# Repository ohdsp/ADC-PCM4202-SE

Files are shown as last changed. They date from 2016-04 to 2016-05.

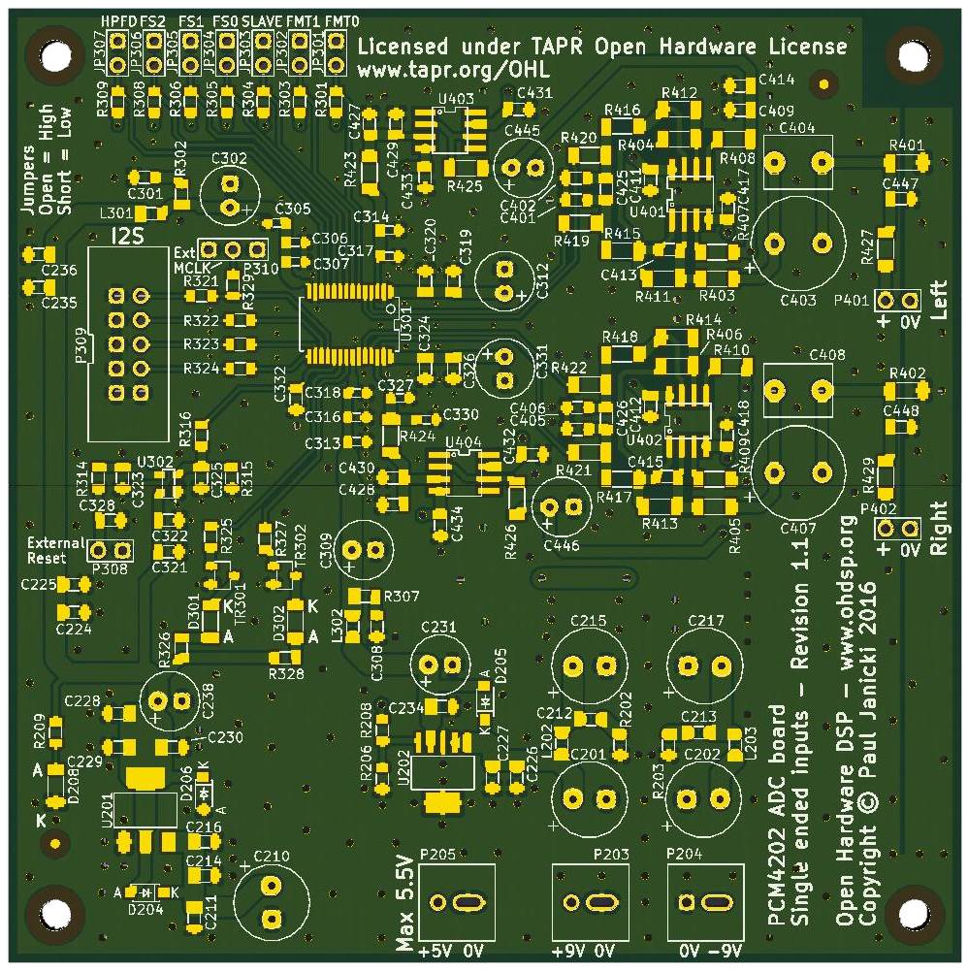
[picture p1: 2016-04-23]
ADC-PCM4202-SE.jpg

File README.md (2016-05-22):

# [Open Hardware DSP Platform](http://www.ohdsp.org)
## PCM4202 ADC with single ended inputs
### Revision 1.1
###### ADC-PCM4202-SE (KiCad 4.0.2-stable)
---
# README
### Disclaimer
Copyright Paul Janicki 2016

Licensed under the TAPR Open Hardware License (www.tapr.org/OHL)

This documentation is distributed WITHOUT ANY EXPRESS OR IMPLIED WARRANTY, INCLUDING OF MERCHANTABILITY, SATISFACTORY QUALITY AND FITNESS FOR A PARTICULAR PURPOSE.

### What is this repository?

**Quick summary**

This is a single ended stereo input PCM4202 ADC. This is designed as part the Open Hardware DSP Platform.  

The PCM4202 is a hardware controlled Delta-Sigma ADC.

This repository contains the KiCad design files, manufacturing Gerber/drill files, and PDF/drawing files for this board.

### What is the project folder structure?
Starting from the top level: \
*ADC-PCM4202-SE*
+ *Bill of Materials*  - This contains the bill of materials in CVS, LibreOffice Calc and XML formats
+ *Drawings*
    + *PCB* - This contains SVG and PDF outputs of PCB copper layers and assembly drawings
    + *Schematics* - This contains the PDF schematic drawing
+ *Gerbers* - This contains the PCB Gerbers and drill drawings for manufacture, there is also a zip file ready to send to most manufacturers
+ *KiCad* - This contains the original KiCad schematic and PCB design files

### How do I get set up?

**Summary of set up**

1. Set your self up a directory on a local disk, something simple will make life easier (eg C:\Electronics on Windows as used here), but anywhere will do just fine.
2. Download the Kicad-Libs from [https://github.com/ohdsp/KiCad-Libs](https://github.com/ohdsp/KiCad-Libs) and place in C:\Electronics\Kicad-Libs (or your chosen folder) 
3. Create a OHDSP subdirectory in C:\Electronics (so C:\Electronics\OHDSP)
3. Download this project to C:\Electronics\OHDSP\ADC-PCM4202-SE
4. Fire up Kicad
5. Open the main project file C:\Electronics\OHDSP\ADC-PCM4202-SE\Schematics\ADC-PCM4202-SE.pro
6. (Optional) Setup Pcbnew component library as below.
7. Do as you wish with the project, just keep it under TAPR Open Hardware License

Make sure your git setup doesn't exclude files used in the project (like .LIB files) or things may go wrong down the line.

**KiCad Library Configuration**

Note that you need to setup a Pcbnew library, but the eeschema libraries should work without any changes if you followed the instructions above.

To setup Pcbnew libraries:

In Pcbnew go to Preferences -> Footprint Libraries Manager. Under Global Libraries tab in the top list check if there is a nickname "MyKiCadLibs-Footprints" (usually at the end of the list). If there is but it points to the wrong place then change the Library Path to point to MyKiCadLibs-Footprints (eg C:\Electronics\KiCad-Libs\MyKiCadLibs-Footprints.pretty) folder for your setup. If this is missing you can use "Append with Wizard", choose "Files on my computer", click next, browse to library location (eg C:\Electronics\KiCad-Libs\MyKiCadLibs-Footprints.pretty) and select the folder MyKiCadLibs-Footprints.pretty, click next, check the Status column states OK and the Format is KiCad (if not re-download the library) and click next, then select "To global library configuration..." and click Finish.

To setup eeschema component libraries:
Either from KiCad project window go to Tools -> Run Library Editor OR under eeschema, go to Tools -> Library Editor. Then Preferences -> Component Libraries.

The top section "Component Library Files" should ideally contain only two libraries, the "power" library that ships with KiCad and "MyKiCadLibs-Lib" available from above. To setup MyKiCadLibs-Lib as a relative path under the "User defined search path" click add. Browse to the location of KiCad-Libs you download above (eg C:\Electronics\KiCad-Libs) and click "Select Folder". Say yes to add a relative path. Under component library files click add, browse to the KiCad-libs again (eg C:\Electronics\KiCad-Libs), select file "MyKiCadLibs-Lib.lib" and click open. MyKiCadLibs-lib should appear in the component library list with no path as it will be using the user defined search path set in the box below.

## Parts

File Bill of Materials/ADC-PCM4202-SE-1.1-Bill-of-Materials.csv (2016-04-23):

Reference | Quantity | Footprint | Value | Description | Voltage | Size | Current | Type | Tolerance | Power
C201 C202 C210 C215 C217 | 5 | CAP-TH-D8mmP3.5mm | 220u | 'Aluminium electrolytic low impedance capacitor - eg Panasonic FC or FR parts | '25V | '3.5mm Pitch, 8mm Diameter | ' | ' | ' | '
C203 C204 C211 C218 C219 C226 | 6 | SMD-0805 | 22u | 'Ceramic capacitor | '25V | '0805 | ' | 'X5R | '20% | '
C205 C206 C214 C220 C221 C225 C227 C229 C233 C236 C237 C304 C311 C319 C322 C323 C326 C328 C332 C409 C410 C411 C412 C417 C418 C421 C422 C427 C428 C431 C432 C433 C434 C437 C438 C441 C442 C449 C450 | 39 | SMD-0805 | 100n | 'Ceramic capacitor | '50V | '0805 | ' | 'X7R | '10% | '
C208 C209 C216 C222 C223 C230 C234 C320 C324 C423 C424 C429 C430 C439 C440 C443 C444 | 17 | SMD-0805 | 10n | 'Ceramic capacitor | '50V | '0805 | ' | 'X7R | '10% | '
C207 C212 C213 C301 C308 C401 C402 C405 C406 | 9 | SMD-0805 | 100p | 'Ceramic capacitor | '50V | '0805 | ' | 'C0G | '5% | '
C224 C235 C321 C414 C416 C451 C452 | 7 | SMD-0805 | 10u | 'Ceramic capacitor | '10V | '0805 | ' | 'X5R | '20% | '
C231 C238 C302 C309 C312 C331 | 6 | CAP-TH-D6.3mmP2.5mm | 220u | 'Aluminium electrolytic low impedance capacitor - eg Panasonic FC or FR parts | '10V | '2.5mm Pitch, 6.3mm Diameter | ' | ' | ' | '
C228 C232 C303 C310 C315 C329 | 6 | SMD-0805 | 22u | 'Ceramic capacitor | '10V | '0805 | ' | 'X5R | '20% | '
C305 C313 | 2 | SMD-0603 | 1u | 'Ceramic capacitor | '10V | '0603 | ' | 'X7R | '10% | '
C306 C314 C316 C330 | 4 | SMD-0603 | 100n | 'Ceramic capacitor | '50V | '0603 | ' | 'X7R | '10% | '
C307 C317 C318 C327 | 4 | SMD-0603 | 10n | 'Ceramic capacitor | '50V | '0603 | ' | 'X7R | '10% | '
C325 | 1 | SMD-0805 | N/F | 'Ceramic capacitor | '50V | '0805 | ' | 'X7R | '10% | '
C403 C407 | 2 | CAP-TH-D10mmP5mm | 100u | 'Aluminium electrolytic - Panasonic FC, Audio Grade, or Bipolar part | '50V | '5mm Pitch, 10mm Diameter | ' | ' | ' | '
C404 C408 | 2 | CAP_TH_5mm | 100n | 'Polyester capacitor - 5mm pitch - 5.5mm width max | '63V | '5mm | ' | 'Film | '10% | '
C413 C415 | 2 | SMD-0805 | 330p | 'Ceramic capacitor | '50V | '0805 | ' | 'C0G | '5% | '
C419 C420 C435 C436 | 4 | SMD-1206 | 10u | 'Ceramic capacitor | '35V | '1206 | ' | 'X5R | '20% | '
C425 C426 | 2 | SMD-0805 | 2n7 | 'Ceramic capacitor | '50V | '0805 | ' | 'C0G | '5% | '
C445 C446 | 2 | CAP-TH-D6.3mmP2.5mm | 47u | 'Aluminium electrolytic low impedance capacitor - eg Panasonic FC or FR parts | '10V | '2.5mm Pitch, 6.3mm Diameter | ' | ' | ' | '
C447 C448 | 2 | SMD-0805 | 1n | 'Ceramic capacitor | '50V | '0805 | ' | 'C0G | '5% | '
D201 D202 D203 D204 D205 D206 D207 | 7 | DIODE-SOD-123 | SS14L | 'SS14L 1A 40V Schottky rectifier - Sub-SMA (SOD-123) | ' | ' | ' | ' | ' | '
D208 | 1 | SMD-1206 | Green LED 1206 | 'Green LED - SMD - Vf 1.8V to 2.2V | ' | '1206 | ' | ' | ' | '
D301 D302 | 2 | SMD-1206 | Red LED 1206 | 'Red LED - SMD - Vf 1.8V to 2.2V | ' | '1206 | ' | ' | ' | '
FID1 FID2 FID3 FID4 | 4 | FID-1MM-3MM | MNT_HOLE | 'Fiducial Marker | ' | ' | ' | ' | ' | '
JP301 JP302 JP303 JP304 JP305 JP306 JP307 P308 P401 P402 | 10 | CONN_SIL_2_1MM | CONN_2x1 | '1x2 2.54mm pitch pin header | ' | ' | ' | ' | ' | '
L201 L202 L203 L301 L302 | 5 | SMD-0805 | 600R@100MHz | 'Ferrite bead, current rating 0.3A or higher, 600R@100MHz | ' | '0805 | '=>0.3A | ' | ' | '
MNT201 MNT202 MNT203 MNT204 | 4 | MNT_HOLE_3.2mm | MNT_HOLE | 'Mounting Hole | ' | ' | ' | ' | ' | '
P203 P204 P205 | 3 | CONN-2WAY-2.54mm-3.81mm-SPACING | CONN_2x1 | '2 way screw terminal, any 2.54mm to 3.81mm pitch part | ' | ' | ' | ' | ' | '
P309 | 1 | CONN_DIL_2X5_BOX_1MM | CONN_02X05 | '2x5 2.54mm pitch box header | ' | ' | ' | ' | ' | '
P310 | 1 | CONN_SIL_3_1MM | N/F | '1x3 2.54mm pitch pin header | ' | ' | ' | ' | ' | '
R201 R202 R203 R302 R307 | 5 | SMD-0805 | 47 | 'Thick or thin film resistor | ' | '0805 | ' | ' | '1% | '100mW
R206 | 1 | SMD-0805 | 2k2 | 'Thick or thin film resistor | ' | '0805 | ' | ' | '1% | '100mW
R208 | 1 | SMD-0805 | 6k8 | 'Thick or thin film resistor | ' | '0805 | ' | ' | '1% | '100mW
R209 R326 R328 | 3 | SMD-0805 | 470 | 'Thick or thin film resistor | ' | '0805 | ' | ' | '1% | '100mW
R301 R303 R304 R305 R306 R308 R309 | 7 | SMD-0805 | 10k | 'Thick or thin film resistor | ' | '0805 | ' | ' | '1% | '100mW
R315 | 1 | SMD-0805 | 100k | 'Thick or thin film resistor | ' | '0805 | ' | ' | '1% | '100mW
R316 | 1 | SMD-0805 | 100R | 'Thick or thin film resistor | ' | '0805 | ' | ' | '1% | '100mW
R321 R322 R323 | 3 | SMD-0805 | 0 | 'Thick or thin film resistor | ' | '0805 | ' | ' | '1% | '100mW
R324 | 1 | SMD-0805 | 75 | 'Thick or thin film resistor | ' | '0805 | ' | ' | '1% | '100mW
R314 R325 R327 | 3 | SMD-0805 | 1k | 'Thick or thin film resistor | ' | '0805 | ' | ' | '1% | '100mW
R310 R317 R318 R319 R320 R329 | 6 | SMD-0805 | N/F | 'Thick or thin film resistor | ' | '0805 | ' | ' | '1% | '100mW
R401 R402 | 2 | SMD-1206 | 47k | 'MELF0204 1% =>250mW or 1206 1% =>250mW | ' | '1206 | ' | ' | '1% | '250mW
R407 R408 R409 R410 R411 R413 | 6 | SMD-1206 | 2k2 | 'MELF0204 1% =>250mW or 1206 1% =>250mW | ' | '1206 | ' | ' | '1% | '250mW
R404 R406 R412 R414 | 4 | SMD-1206 | 1k5 | 'MELF0204 1% =>250mW or 1206 1% =>250mW | ' | '1206 | ' | ' | '1% | '250mW
R415 R416 R417 R418 | 4 | SMD-1206 | 40R2 | 'MELF0204 1% =>250mW or 1206 1% =>250mW | ' | '1206 | ' | ' | '1% | '250mW
R419 R420 | 2 | SMD-1206 | 100 | 'MELF0204 1% =>250mW or 1206 1% =>250mW | ' | '1206 | ' | ' | '1% | '250mW
R421 R422 | 2 | SMD-1206 | 100R | 'MELF0204 1% =>250mW or 1206 1% =>250mW | ' | '1206 | ' | ' | '1% | '250mW
R403 R405 R423 R424 R425 R426 R427 R429 | 8 | SMD-1206 | 1k | 'MELF0204 1% =>250mW or 1206 1% =>250mW | ' | '1206 | ' | ' | '1% | '250mW
TR301 TR302 | 2 | IC-SOT23 | BC847 | '45 V, 100 mA NPN general-purpose transistors | ' | ' | ' | ' | ' | '
U201 | 1 | IC-SOT-223 | TLV1117LV33DCY | 'TLV1117LV 1-A, Positive Fixed-Voltage, Low-Dropout Regulator - Fixed 3V3 | ' | ' | ' | ' | ' | '
U202 | 1 | IC-SOT223-6 | TPS7A4501 | 'TPS7A45xx Low-Noise Fast-Transient-Response 1.5-A Low-Dropout Voltage Regulator - Adjustable | ' | ' | ' | ' | ' | '
U301 | 1 | IC-SSOP28 | PCM4202DBT | 'High-Performance 24-Bit, 216kHz Sampling Stereo Audio Analog-to-Digital Converter | ' | ' | ' | ' | ' | '
U302 | 1 | IC-SOT143 | ADM811TART | 'Microprocessor Supervisory - 3V08 Typical Threshold | ' | ' | ' | ' | ' | '
U401 U402 | 2 | IC_SOIC_8 | TLE2072 | 'LOW-NOISE HIGH-SPEED JFET-INPUT OPERATIONAL AMPLIFIERS - DUAL | ' | ' | ' | ' | ' | '
U403 U404 | 2 | IC_SOIC_8 | TLE2071 | 'LOW-NOISE HIGH-SPEED JFET-INPUT OPERATIONAL AMPLIFIERS - SINGLE | ' | ' | ' | ' | ' | '

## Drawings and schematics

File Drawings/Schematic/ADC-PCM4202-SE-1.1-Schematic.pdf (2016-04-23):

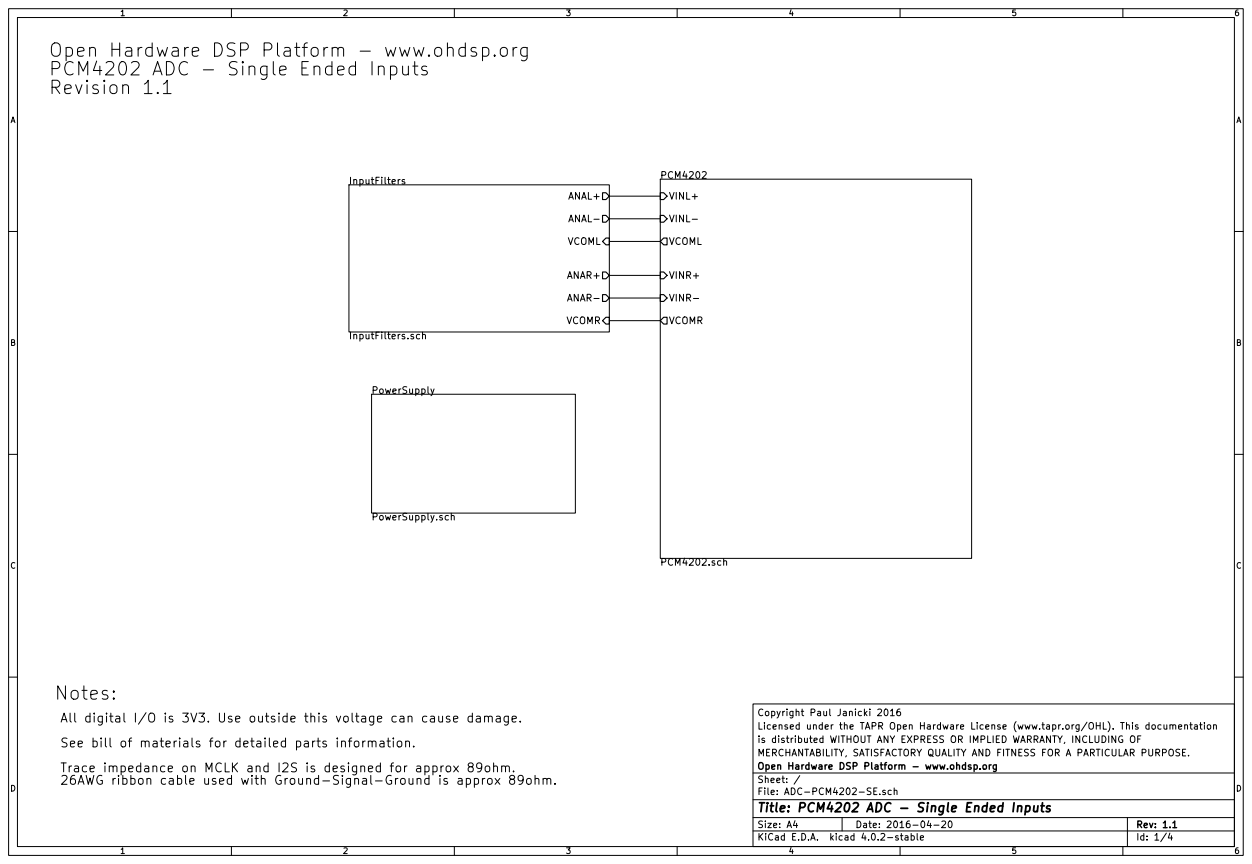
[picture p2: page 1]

Open Hardware DSP Platform - www.ohdsp.org
PCM4202 ADC - Single Ended Inputs
Revision 1.1

PCM4202
PCM4202.sch VINR+ VINR- VINL+ VINL- VCOML

VCOML ANAL+ ANAL- ANAR+ ANAR- VCOMR

All digital I/O is 3V3. Use outside this voltage can cause damage.
See bill of materials for detailed parts information.
Trace impedance on MCLK and I2S is designed for approx 89ohm.
26AWG ribbon cable used with Ground-Signal-Ground is approx 89ohm.

Copyright Paul Janicki 2016
Licensed under the TAPR Open Hardware License (www.tapr.org/OHL). This documentation
is distributed WITHOUT ANY EXPRESS OR IMPLIED WARRANTY, INCLUDING OF
MERCHANTABILITY, SATISFACTORY QUALITY AND FITNESS FOR A PARTICULAR PURPOSE.
File: ADC-PCM4202-SE.sch Sheet: / Open Hardware DSP Platform - www.ohdsp.org

Id: 1/4 Title: PCM4202 ADC - Single Ended Inputs

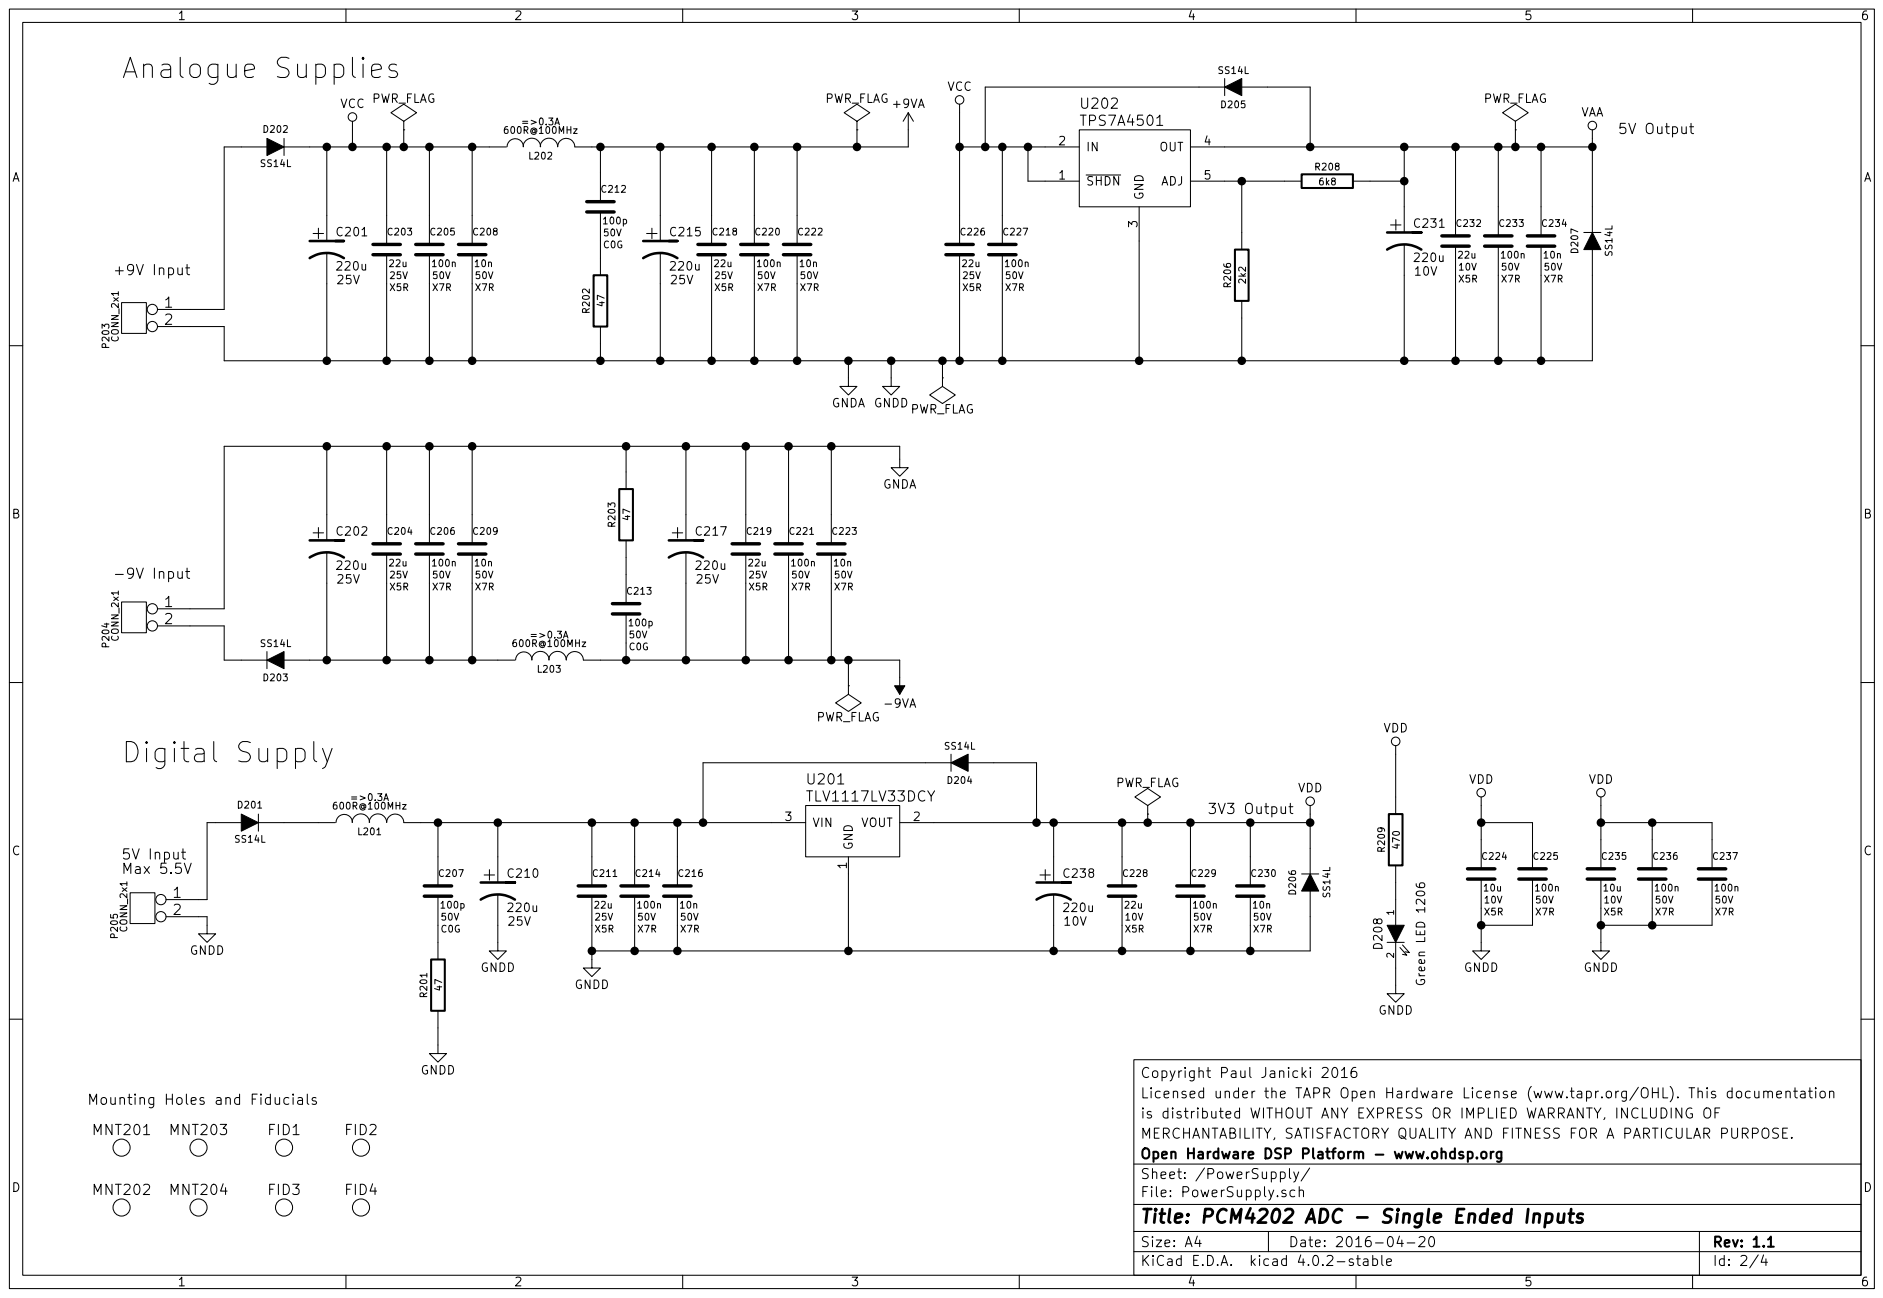
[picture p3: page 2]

Copyright Paul Janicki 2016
Licensed under the TAPR Open Hardware License (www.tapr.org/OHL). This documentation
is distributed WITHOUT ANY EXPRESS OR IMPLIED WARRANTY, INCLUDING OF
MERCHANTABILITY, SATISFACTORY QUALITY AND FITNESS FOR A PARTICULAR PURPOSE.
Open Hardware DSP Platform - www.ohdsp.org
Sheet: /PowerSupply/
File: PowerSupply.sch
Id: 2/4 Title: PCM4202 ADC - Single Ended Inputs

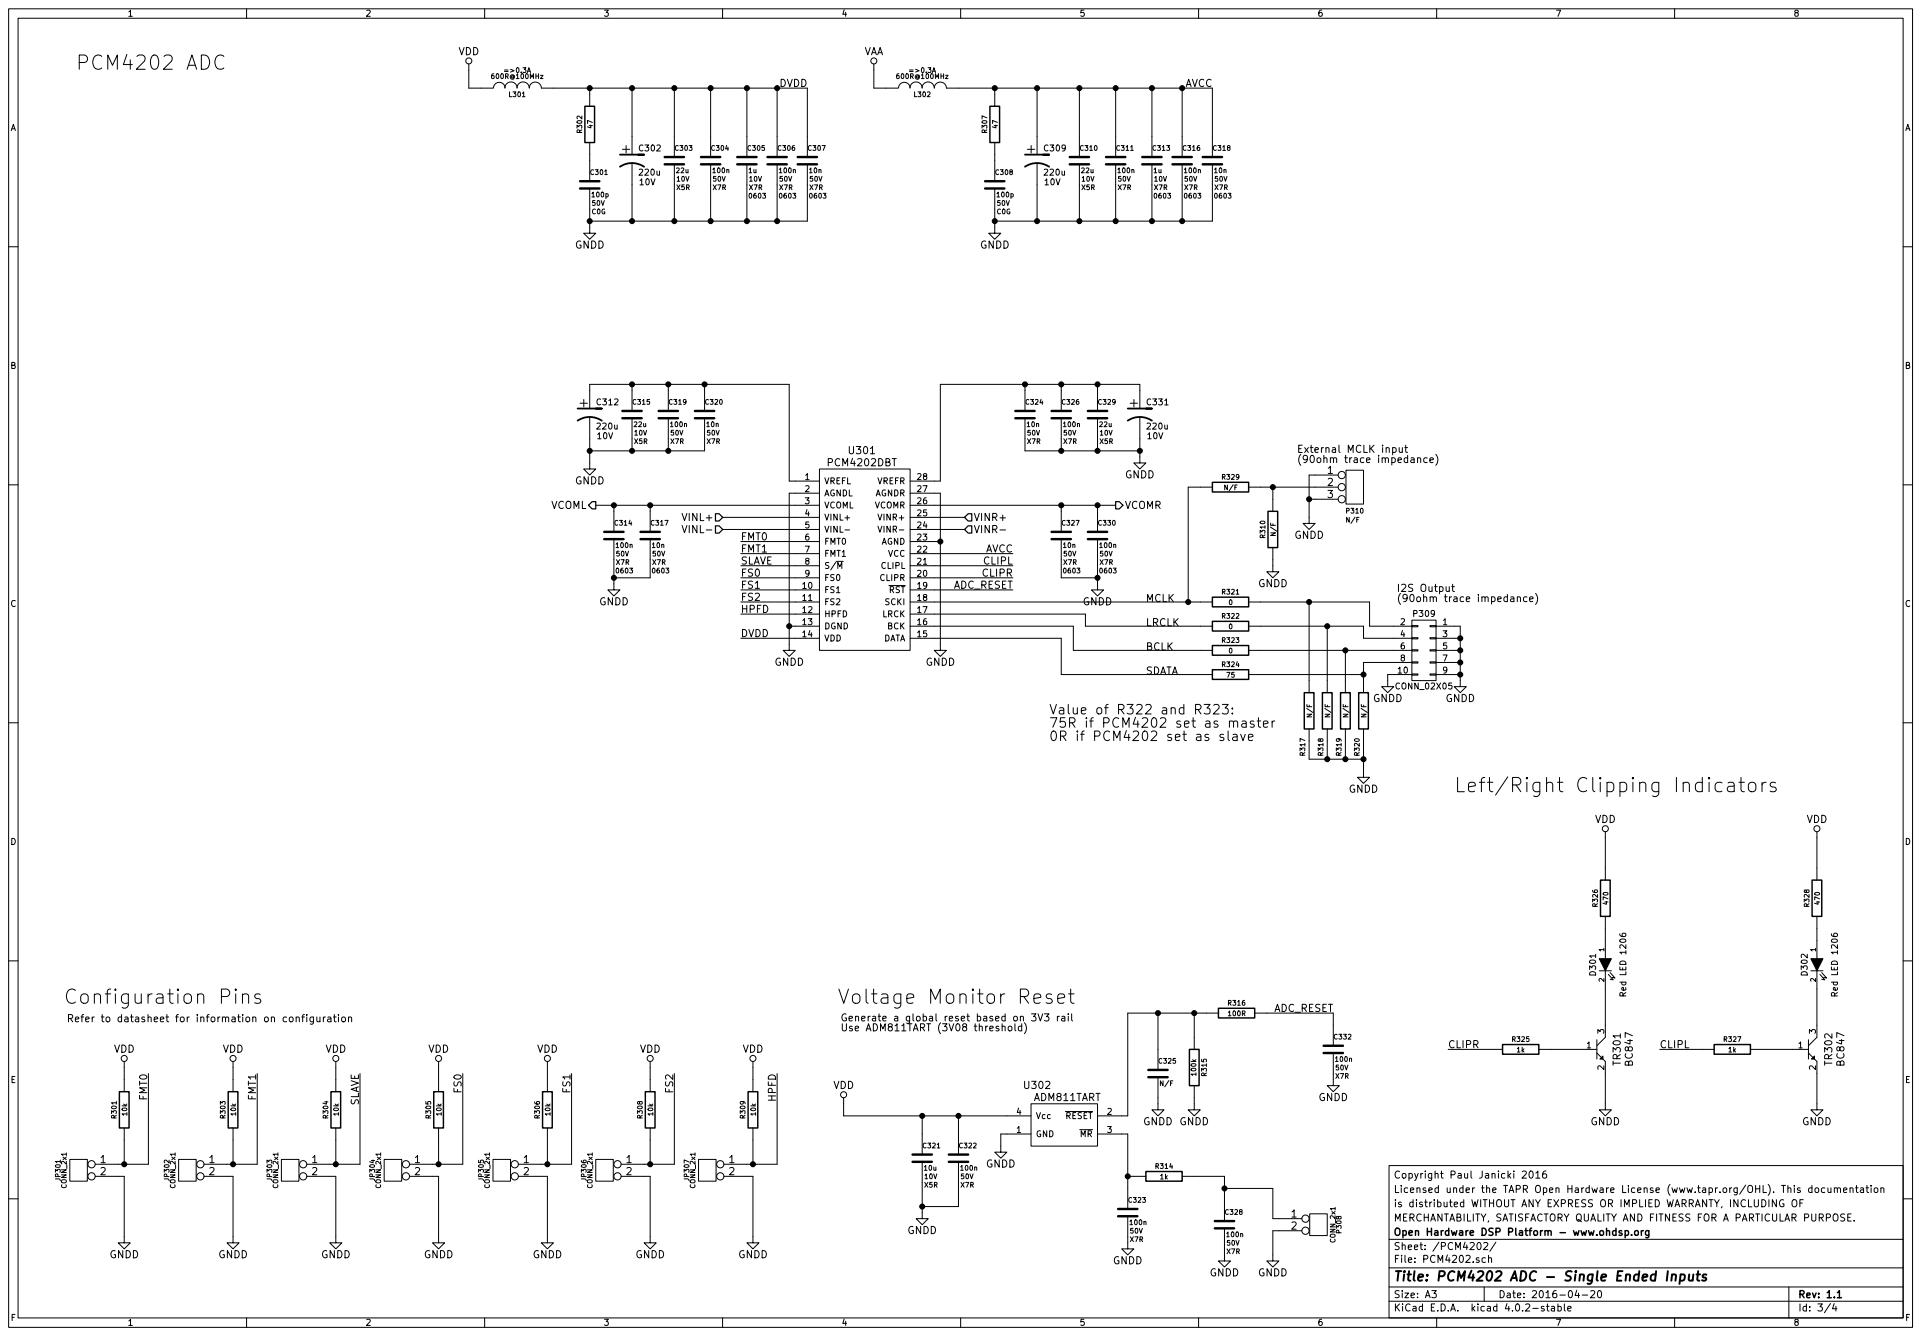
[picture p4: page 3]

VINR+ VINR- VINL+ VINL-

CLIPR

FS1 | | ADC_RESET

Value of R322 and R323:
75R if PCM4202 set as master
0R if PCM4202 set as slave

Left/Right Clipping Indicators

1 2 D301 Red LED 1206 VDD GNDD

Refer to datasheet for information on configuration

Generate a global reset based on 3V3 rail
Use ADM811TART (3V08 threshold)

Copyright Paul Janicki 2016
Licensed under the TAPR Open Hardware License (www.tapr.org/OHL). This documentation
is distributed WITHOUT ANY EXPRESS OR IMPLIED WARRANTY, INCLUDING OF
MERCHANTABILITY, SATISFACTORY QUALITY AND FITNESS FOR A PARTICULAR PURPOSE.
File: PCM4202.sch Sheet: /PCM4202/ Open Hardware DSP Platform - www.ohdsp.org

Id: 3/4 Title: PCM4202 ADC - Single Ended Inputs

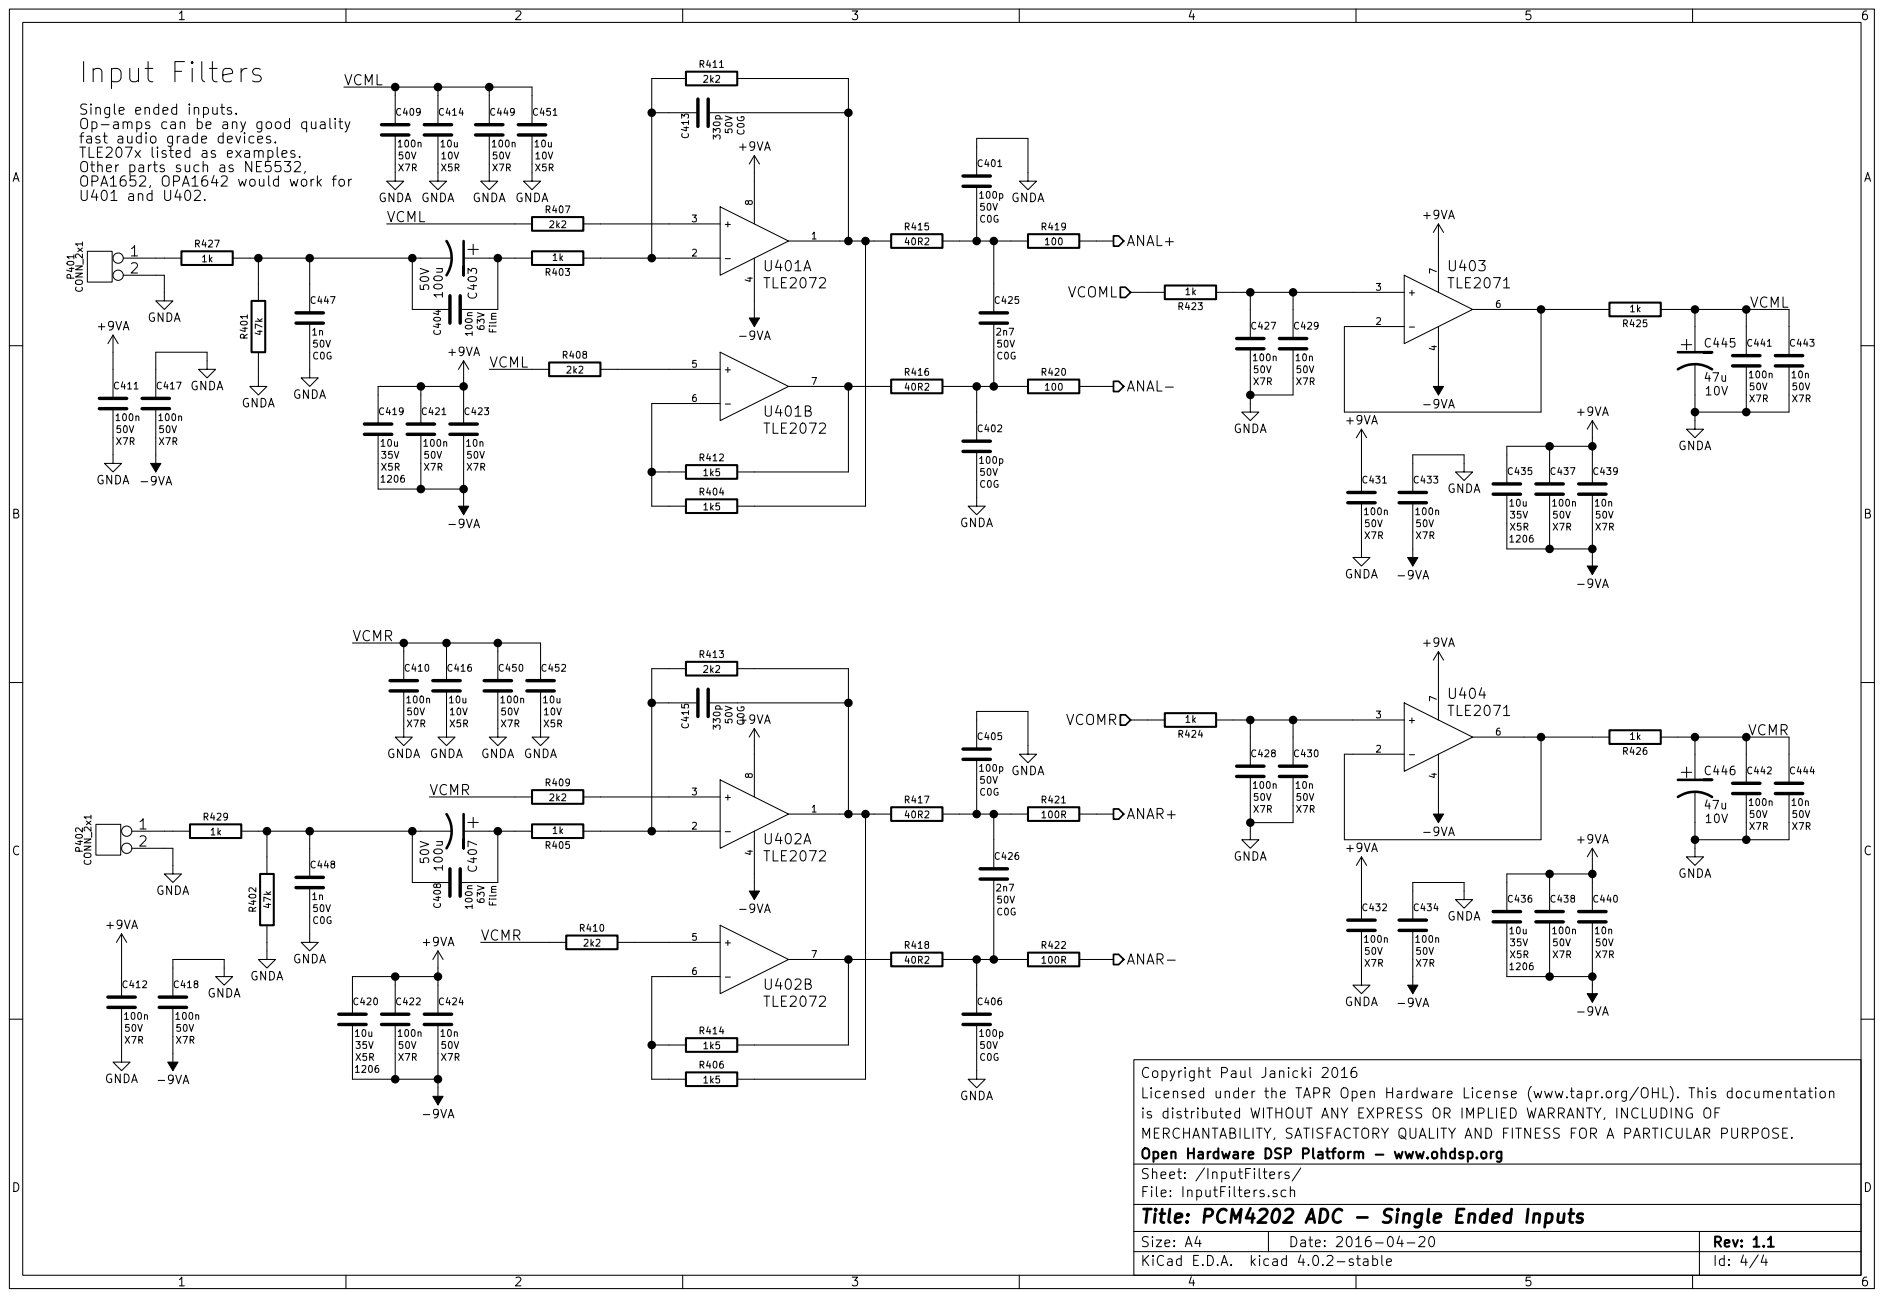
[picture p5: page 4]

GNDA GNDA

Single ended inputs.
Op-amps can be any good quality
fast audio grade devices.
TLE207x listed as examples.
Other parts such as NE5532,

Copyright Paul Janicki 2016 GNDA

Licensed under the TAPR Open Hardware License (www.tapr.org/OHL). This documentation
is distributed WITHOUT ANY EXPRESS OR IMPLIED WARRANTY, INCLUDING OF
MERCHANTABILITY, SATISFACTORY QUALITY AND FITNESS FOR A PARTICULAR PURPOSE.
Open Hardware DSP Platform - www.ohdsp.org
Sheet: /InputFilters/
File: InputFilters.sch
Id: 4/4 Title: PCM4202 ADC - Single Ended Inputs

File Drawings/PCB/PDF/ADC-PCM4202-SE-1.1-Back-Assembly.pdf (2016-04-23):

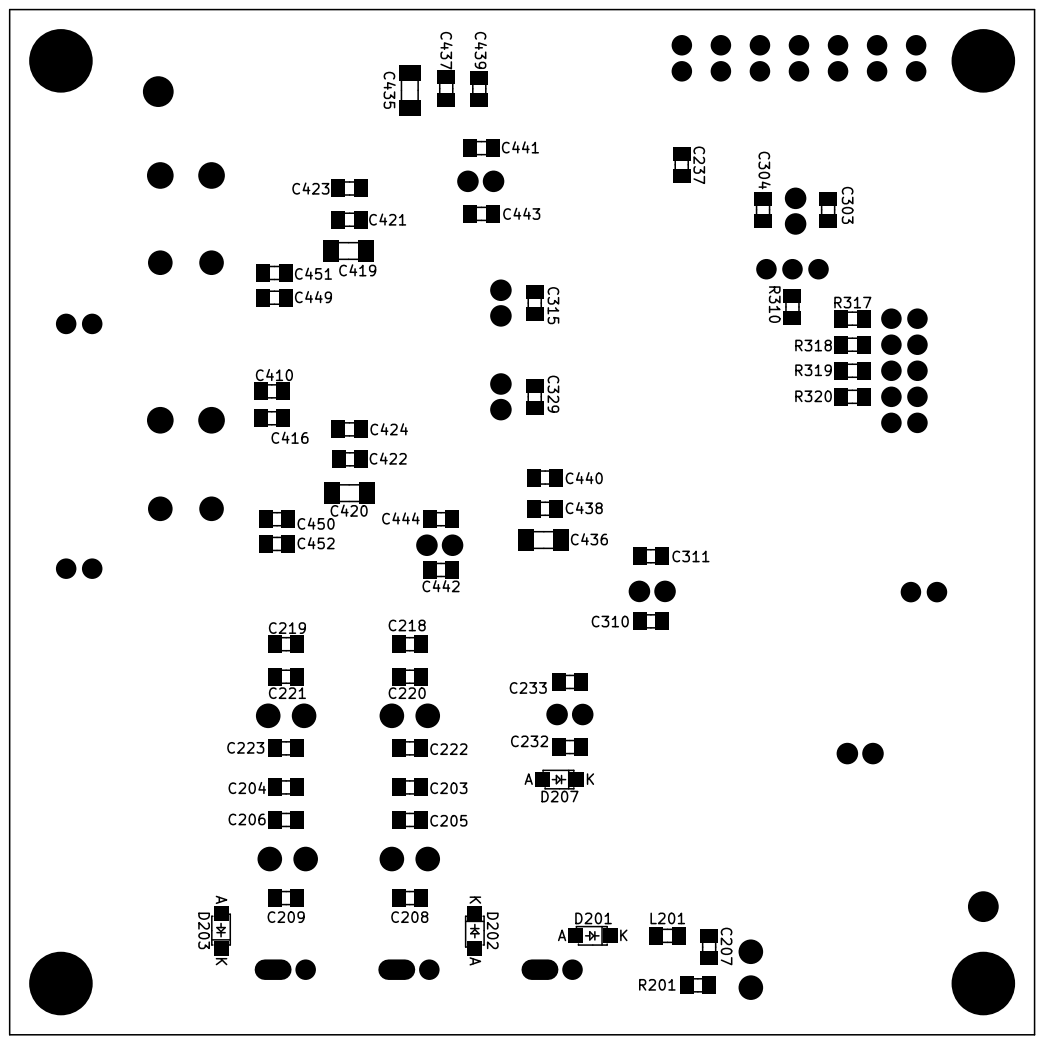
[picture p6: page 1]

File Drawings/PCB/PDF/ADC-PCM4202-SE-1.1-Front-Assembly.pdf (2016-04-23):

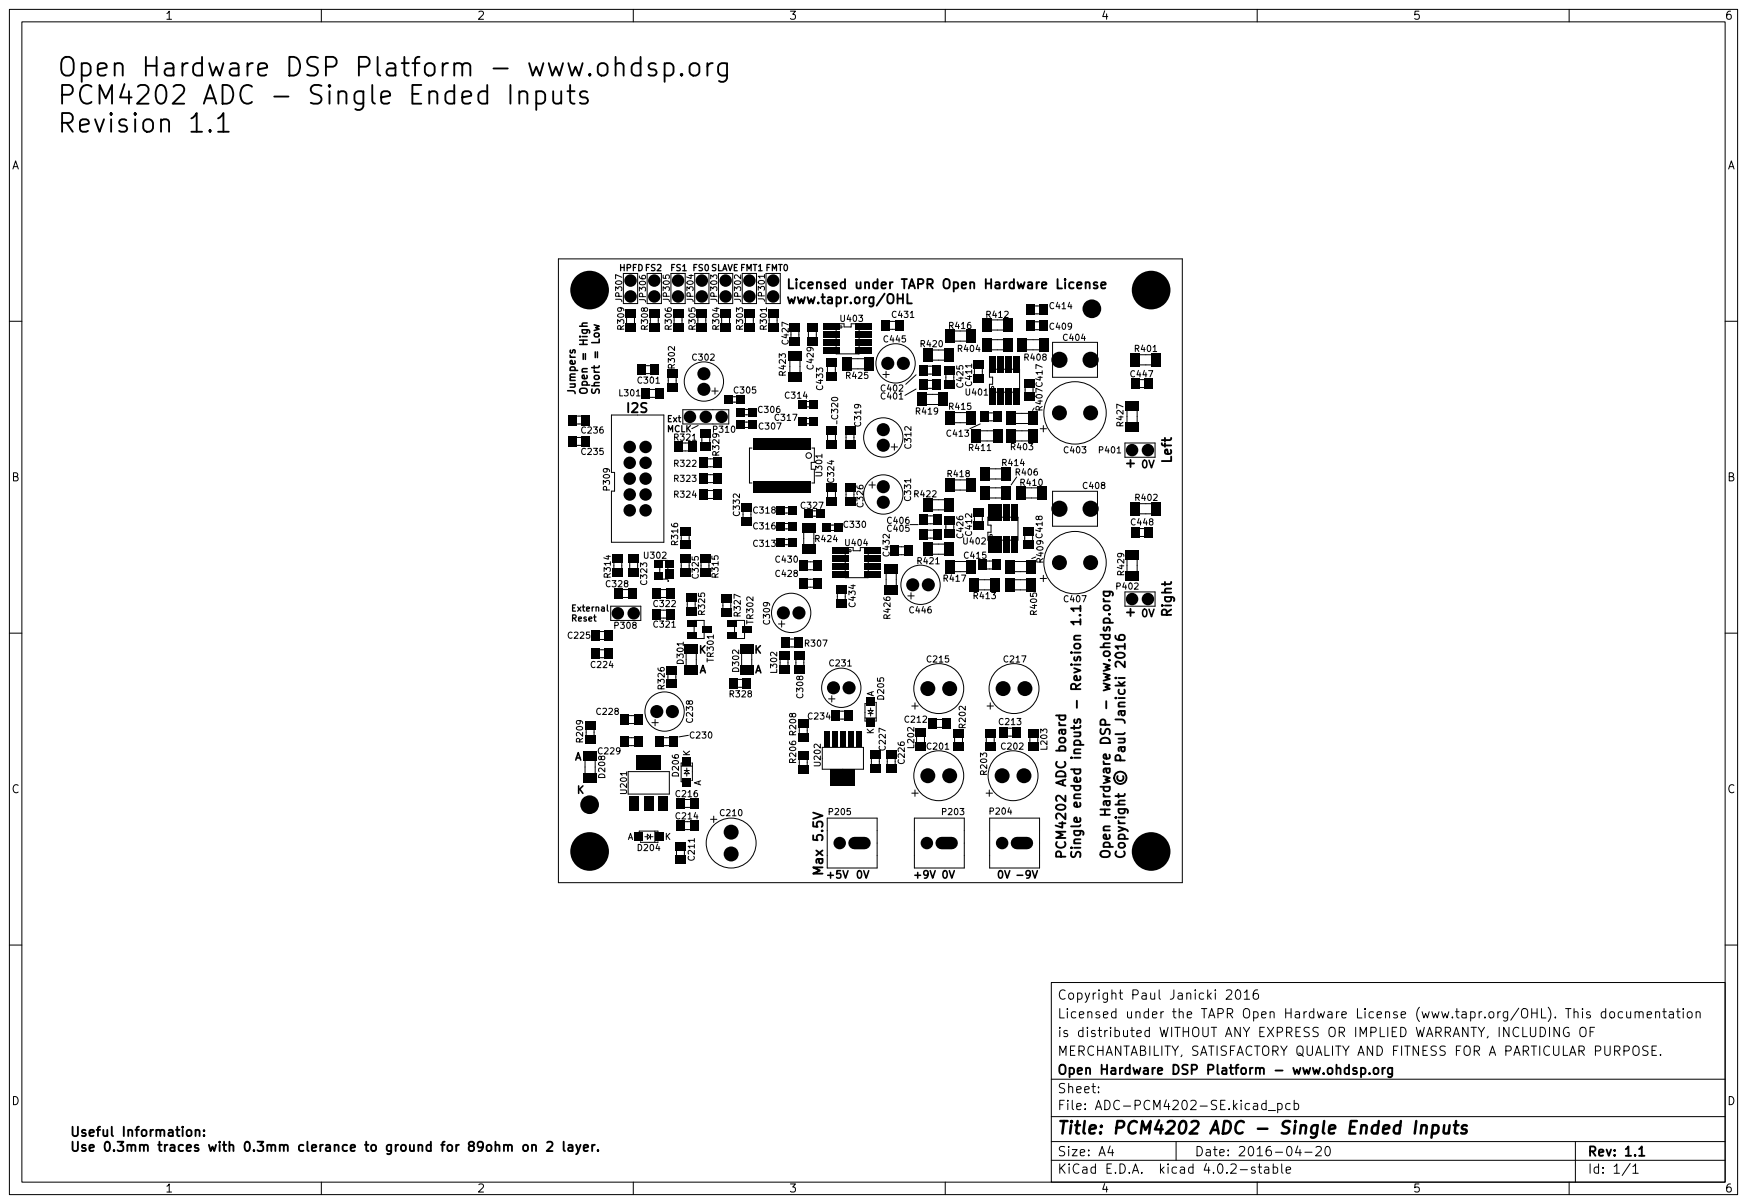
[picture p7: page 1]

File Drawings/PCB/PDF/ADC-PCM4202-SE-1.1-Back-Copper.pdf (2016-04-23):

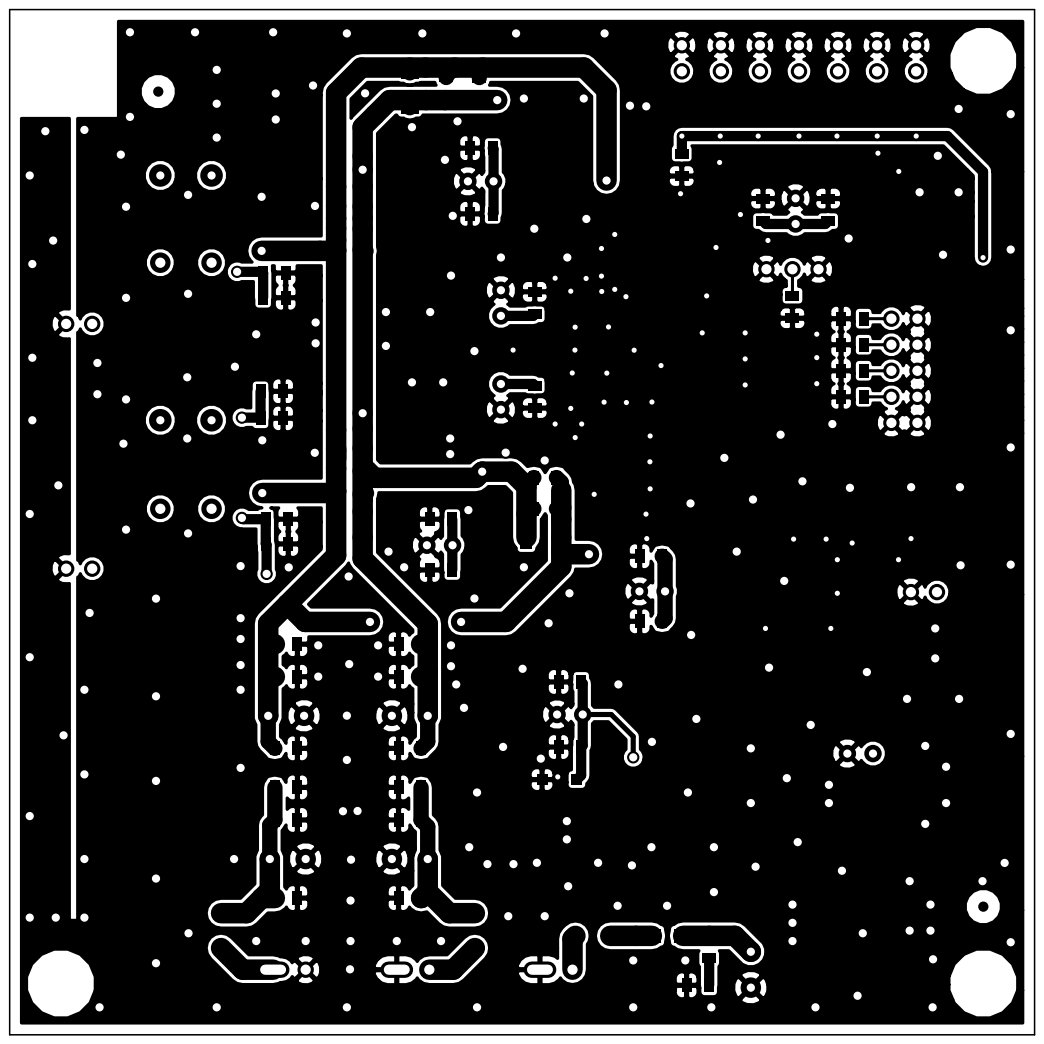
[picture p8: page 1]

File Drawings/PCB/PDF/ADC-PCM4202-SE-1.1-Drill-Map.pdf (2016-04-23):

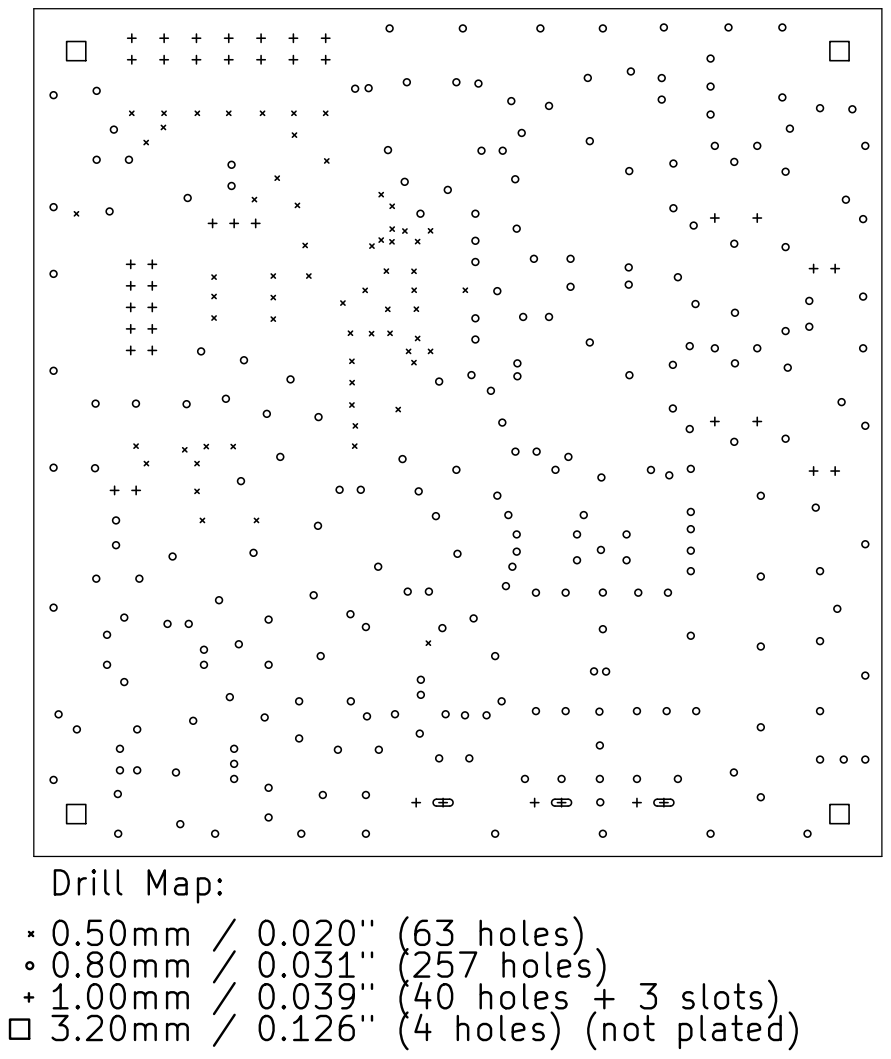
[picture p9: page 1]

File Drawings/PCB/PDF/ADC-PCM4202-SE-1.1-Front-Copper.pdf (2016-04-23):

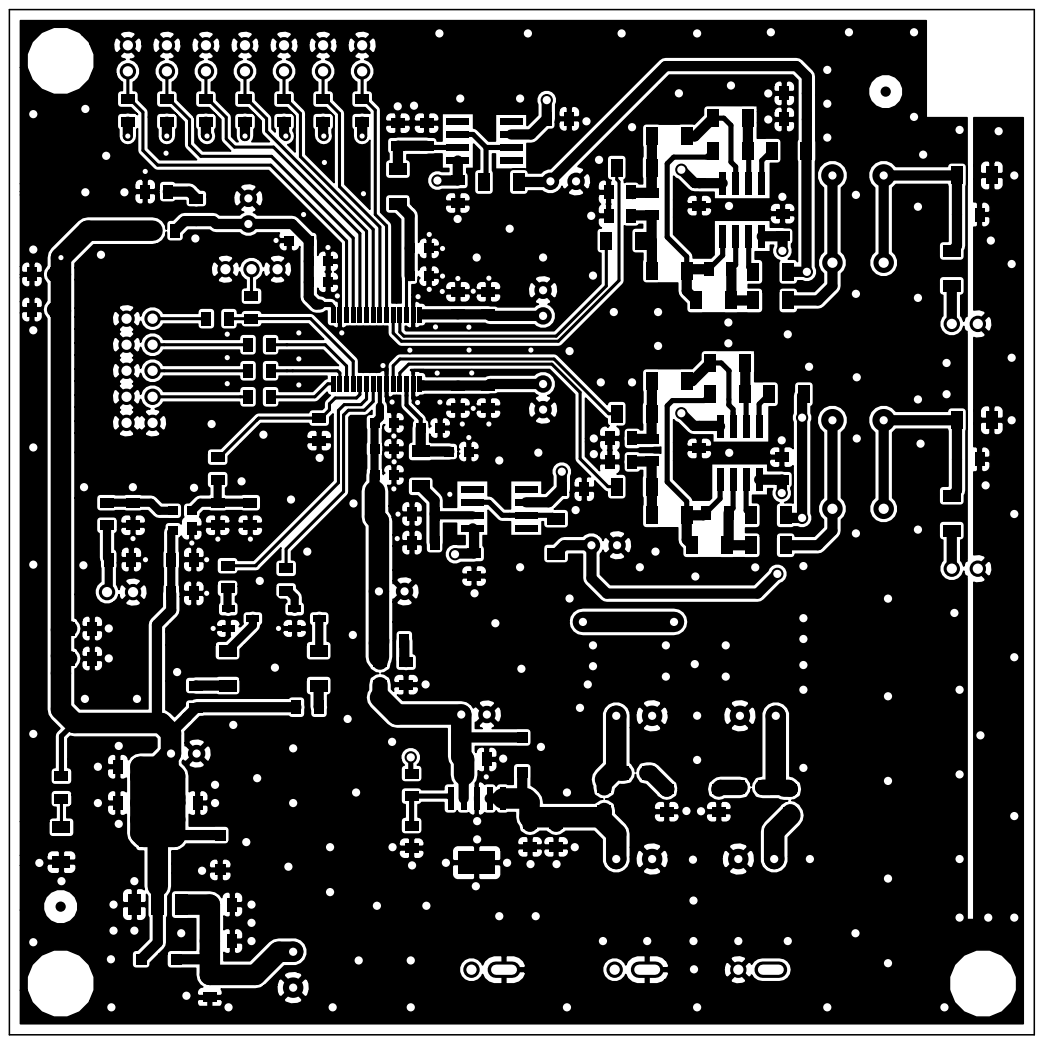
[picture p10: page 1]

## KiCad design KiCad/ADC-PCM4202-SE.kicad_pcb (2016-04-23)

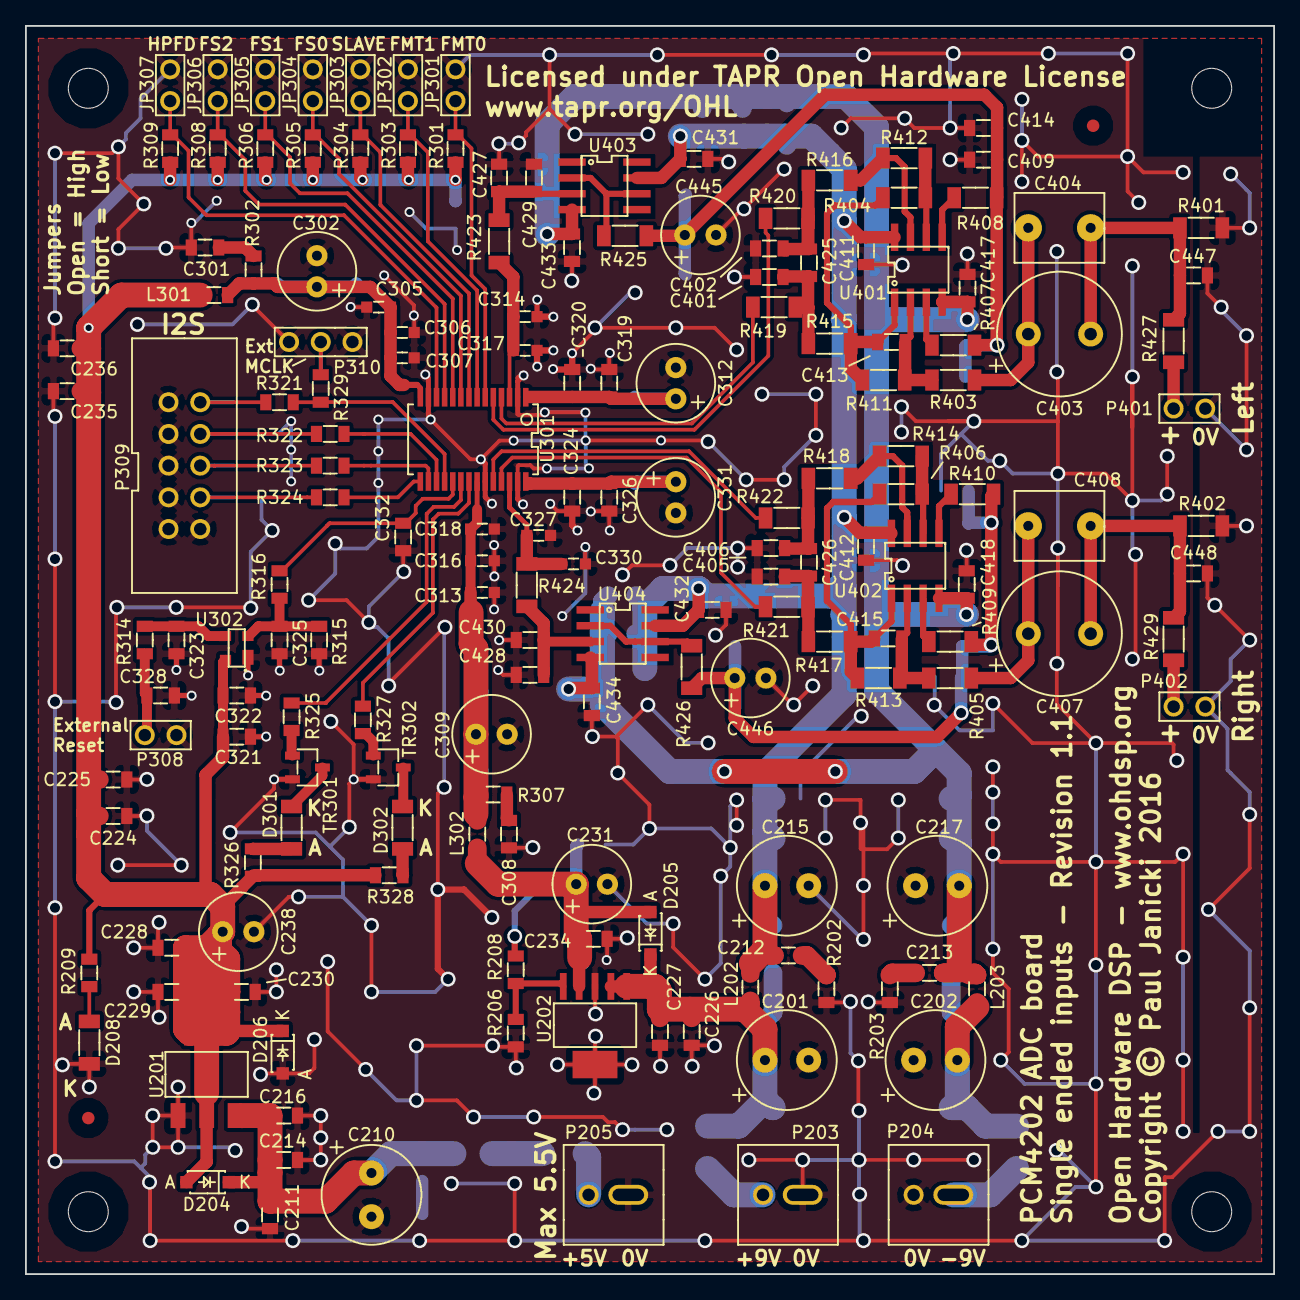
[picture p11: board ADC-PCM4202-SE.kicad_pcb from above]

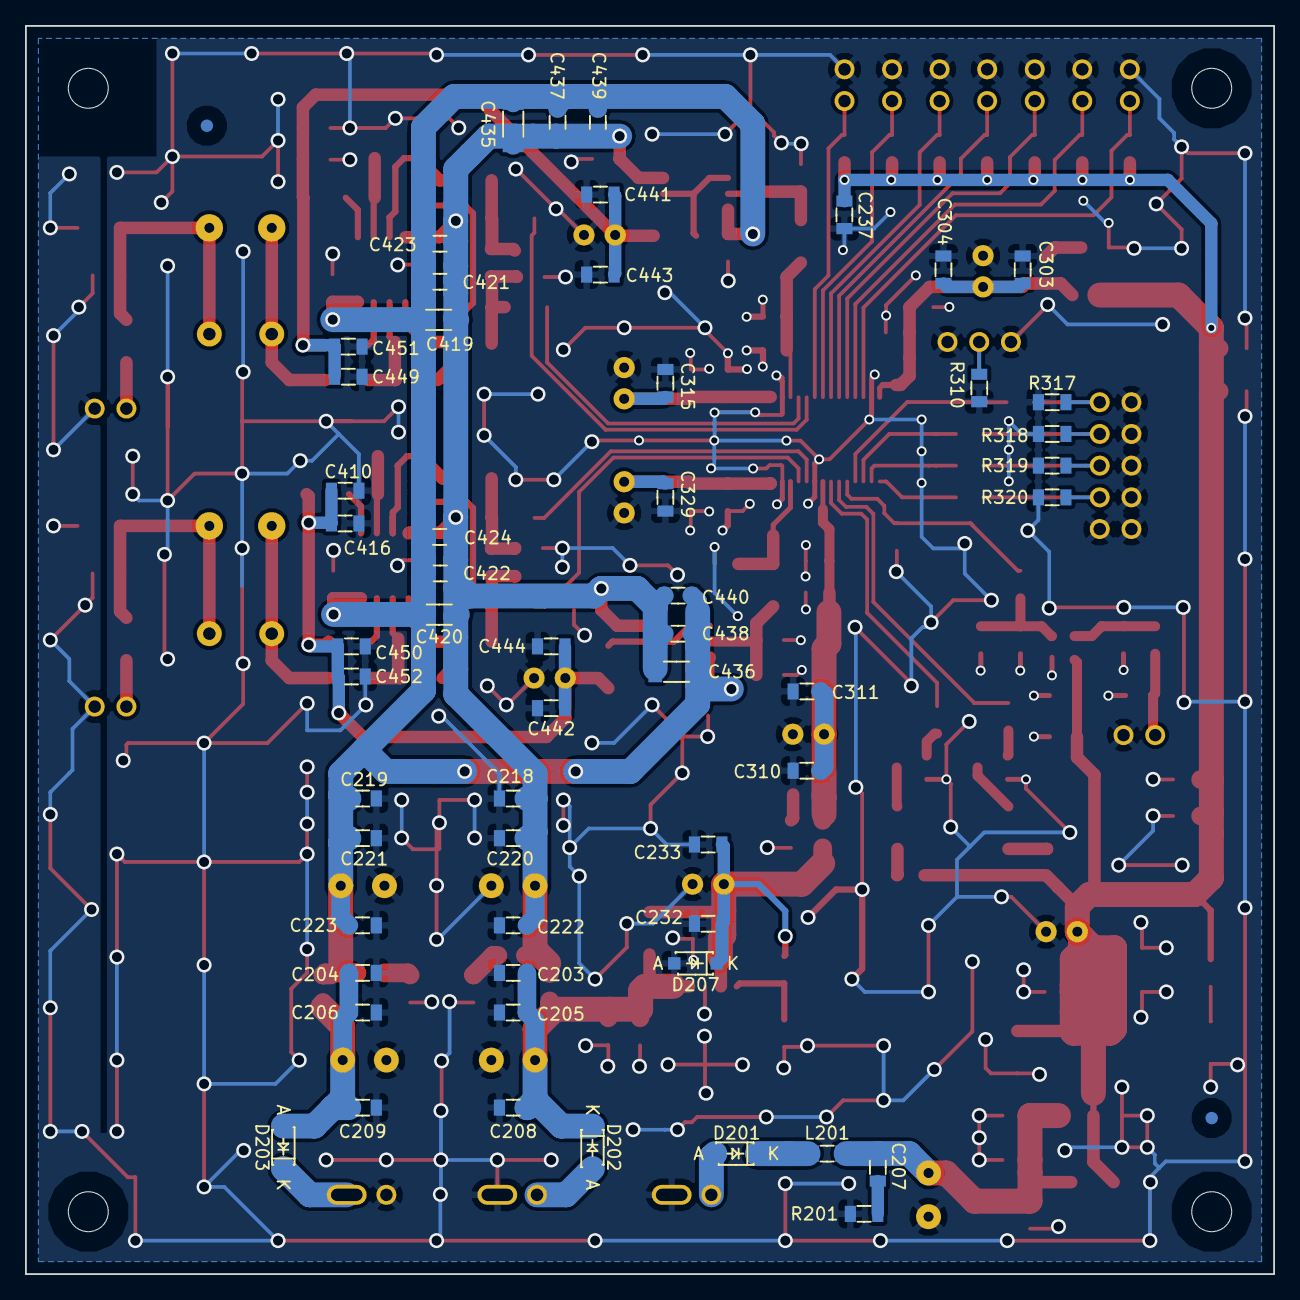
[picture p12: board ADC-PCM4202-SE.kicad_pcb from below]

Board: 2 copper layers, 100.0 x 100.0 mm, 230 parts (57 on the bottom side), 85 nets.

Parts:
C201, C202, C210, C215, C217: 220u; CAP-TH-D8mmP3.5mm
C203, C204, C211, C218, C219, C226, C228, C232, C303, C310, C315, C329: 22u; SMD-0805
C205, C206, C214, C220, C221, C225, C227, C229, C233, C236, C237, C304, C311, C319, C322, C323, C326, C328, C332, C409, C410, C411, C412, C417, C418, C421, C422, C427, C428, C431, C432, C433, C434, C437, C438, C441, C442, C449, C450: 100n; SMD-0805
C207, C212, C213, C301, C308, C401, C402, C405, C406: 100p; SMD-0805
C208, C209, C216, C222, C223, C230, C234, C320, C324, C423, C424, C429, C430, C439, C440, C443, C444: 10n; SMD-0805
C224, C235, C321, C414, C416, C451, C452: 10u; SMD-0805
C231, C238, C302, C309, C312, C331: 220u; CAP-TH-D6.3mmP2.5mm
C305, C313: 1u; SMD-0603
C306, C314, C316, C330: 100n; SMD-0603
C307, C317, C318, C327: 10n; SMD-0603
C325: N/F; SMD-0805
C403, C407: 100u; CAP-TH-D10mmP5mm
C404, C408: 100n; CAP_TH_5mm
C413, C415: 330p; SMD-0805
C419, C420, C435, C436: 10u; SMD-1206
C425, C426: 2n7; SMD-0805
C445, C446: 47u; CAP-TH-D6.3mmP2.5mm
C447, C448: 1n; SMD-0805
D201, D202, D203, D204, D205, D206, D207: SS14L; DIODE-SOD-123
D208: Green LED 1206; SMD-1206
D301, D302: Red LED 1206; SMD-1206
FID1, FID2, FID3, FID4: MNT_HOLE; FID-1MM-3MM
JP301, JP302, JP303, JP304, JP305, JP306, JP307: CONN_2x1; CONN_SIL_2_1MM
L201, L202, L203, L301, L302: 600R@100MHz; SMD-0805
MNT201, MNT202, MNT203, MNT204: MNT_HOLE; MNT_HOLE_3.2mm
P203, P204, P205: CONN_2x1; CONN-2WAY-2.54mm-3.81mm-SPACING
P308, P401, P402: CONN_2x1; CONN_SIL_2_1MM
P309: CONN_02X05; CONN_DIL_2X5_BOX_1MM
P310: N/F; CONN_SIL_3_1MM
R201, R202, R203, R302, R307: 47; SMD-0805
R206: 2k2; SMD-0805
R208: 6k8; SMD-0805
R209, R326, R328: 470; SMD-0805
R301, R303, R304, R305, R306, R308, R309: 10k; SMD-0805
R310, R317, R318, R319, R320, R329: N/F; SMD-0805
R314, R325, R327: 1k; SMD-0805
R315: 100k; SMD-0805
R316: 100R; SMD-0805
R321, R322, R323: 0; SMD-0805
R324: 75; SMD-0805
R401, R402: 47k; SMD-1206
R403, R405, R423, R424, R425, R426, R427, R429: 1k; SMD-1206
R404, R406, R412, R414: 1k5; SMD-1206
R407, R408, R409, R410, R411, R413: 2k2; SMD-1206
R415, R416, R417, R418: 40R2; SMD-1206
R419, R420: 100; SMD-1206
R421, R422: 100R; SMD-1206
TR301, TR302: BC847; IC-SOT23
U201: TLV1117LV33DCY; IC-SOT-223
U202: TPS7A4501; IC-SOT223-6
U301: PCM4202DBT; IC-SSOP28
U302: ADM811TART; IC-SOT143
U401, U402: TLE2072; IC_SOIC_8
U403, U404: TLE2071; IC_SOIC_8

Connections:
+9VA: C212.1, C215.1, C218.1, C220.1, C222.1, C411.1, C412.1, C419.1, C420.1, C421.1, C422.1, C423.1, C424.1, C431.1, C432.1, C435.1, C436.1, C437.1, C438.1, C439.1, C440.1, L202.2, U401.8, U402.8, U403.7, U404.7
-9VA: C213.2, C217.2, C219.2, C221.2, C223.2, C417.2, C418.2, C419.2, C420.2, C421.2, C422.2, C423.2, C424.2, C433.2, C434.2, C435.2, C436.2, C437.2, C438.2, C439.2, C440.2, L203.2, U401.4, U402.4, U403.4, U404.4
/InputFilters/ANAL+: R419.1, U301.4
/InputFilters/ANAL-: R420.1, U301.5
/InputFilters/ANAR+: R421.1, U301.25
/InputFilters/ANAR-: R422.1, U301.24
/InputFilters/VCML: C409.1, C414.1, C441.1, C443.1, C445.1, C449.1, C451.1, R407.2, R408.2, R425.1
/InputFilters/VCMR: C410.1, C416.1, C442.1, C444.1, C446.1, C450.1, C452.1, R409.2, R410.2, R426.1
/InputFilters/VCOML: C314.1, C317.1, R423.2, U301.3
/InputFilters/VCOMR: C327.1, C330.1, R424.2, U301.26
/PCM4202/ADC_RESET: C332.1, R316.1, U301.19
/PCM4202/AVCC: C309.1, C310.1, C311.1, C313.1, C316.1, C318.1, L302.2, R307.1, U301.22
/PCM4202/CLIPL: R327.1, U301.21
/PCM4202/CLIPR: R325.1, U301.20
/PCM4202/DVDD: C302.1, C303.1, C304.1, C305.1, C306.1, C307.1, L301.2, R302.1, U301.14
/PCM4202/FMT0: JP301.1, R301.2, U301.6
/PCM4202/FMT1: JP302.1, R303.2, U301.7
/PCM4202/FS0: JP304.1, R305.2, U301.9
/PCM4202/FS1: JP305.1, R306.2, U301.10
/PCM4202/FS2: JP306.1, R308.2, U301.11
/PCM4202/HPFD: JP307.1, R309.2, U301.12
/PCM4202/SLAVE: JP303.1, R304.2, U301.8
GNDA: C201.2, C202.1, C203.2, C204.1, C205.2, C206.1, C208.2, C209.1, C210.2, C211.2, C214.2, C215.2, C216.2, C217.1, C218.2, C219.1, C220.2, C221.1, C222.2, C223.1, C224.2, C225.2, C226.2, C227.2, C228.2, C229.2, C230.2, C231.2, C232.2, C233.2, C234.2, C235.2, C236.2, C237.2, C238.2, C301.2, C302.2, C303.2, C304.2, C305.2, C306.2, C307.2, C308.2, C309.2, C310.2, C311.2, C312.2, C313.2, C314.2, C315.2, C316.2, C317.2, C318.2, C319.2, C320.2, C321.2, C322.2, C323.2, C324.2, C325.2, C326.2, C327.2, C328.2, C329.2, C330.2, C331.2, C332.2, C401.1, C402.2, C405.1, C406.2, C409.2, C410.2, C411.2, C412.2, C414.2, C416.2, C417.1, C418.1, C427.2, C428.2, C429.2, C430.2, C431.2, C432.2, C433.1, C434.1, C441.2, C442.2, C443.2, C444.2, C445.2, C446.2, C447.2, C448.2, C449.2, C450.2, C451.2, C452.2, D206.1, D207.1, D208.2, JP301.2, JP302.2, JP303.2, JP304.2, JP305.2, JP306.2, JP307.2, P203.2, P204.1, P205.2, P308.2, P309.1, P309.3, P309.5, P309.7, P309.9, P309.10, P310.1, P310.3, P401.2, P402.2, R201.2, R202.2, R203.1, R206.2, R310.1, R315.1, R317.1, R318.1, R319.1, R320.1, R401.1, R402.1, TR301.2, TR302.2, U201.1, U202.3, U301.2, U301.13, U301.23, U301.27, U302.1
unnamed: C202.2, C204.2, C206.2, C209.2, D203.1, L203.1
unnamed: C207.1, C210.1, C211.1, C214.1, C216.1, D204.2, L201.2, U201.3
unnamed: C207.2, R201.1
unnamed: C212.2, R202.1
unnamed: C213.1, R203.2
unnamed: C301.1, R302.2
unnamed: C308.1, R307.2
unnamed: C312.1, C315.1, C319.1, C320.1, U301.1
unnamed: C323.1, R314.1, U302.3
unnamed: C324.1, C326.1, C329.1, C331.1, U301.28
unnamed: C325.1, R315.2, R316.2, U302.2
unnamed: C328.1, P308.1, R314.2
unnamed: C401.2, C425.1, R415.1, R419.2
unnamed: C402.1, C425.2, R416.1, R420.2
unnamed: C403.1, C404.2, R403.2
unnamed: C403.2, C404.1, C447.1, R401.2, R427.1
unnamed: C405.2, C426.1, R417.1, R421.2
unnamed: C406.1, C426.2, R418.1, R422.2
unnamed: C407.1, C408.2, R405.2
unnamed: C407.2, C408.1, C448.1, R402.2, R429.1
unnamed: C413.1, R403.1, R411.2, U401.2
unnamed: C413.2, R404.1, R411.1, R415.2, U401.1
unnamed: C415.1, R405.1, R413.2, U402.2
unnamed: C415.2, R406.1, R413.1, R417.2, U402.1
unnamed: C427.1, C429.1, R423.1, U403.3
unnamed: C428.1, C430.1, R424.1, U404.3
unnamed: D201.1, P205.1
unnamed: D201.2, L201.1
unnamed: D202.1, P203.1
unnamed: D203.2, P204.2
unnamed: D208.1, R209.1
unnamed: D301.1, R326.1
unnamed: D301.2, TR301.3
unnamed: D302.1, R328.1
unnamed: D302.2, TR302.3
unnamed: P309.2, R317.2, R321.1
unnamed: P309.4, R318.2, R322.1
unnamed: P309.6, R319.2, R323.1
unnamed: P309.8, R320.2, R324.1
unnamed: P310.2, R310.2, R329.1
unnamed: P401.1, R427.2
unnamed: P402.1, R429.2
unnamed: R206.1, R208.2, U202.5
unnamed: R321.2, R329.2, U301.18
unnamed: R322.2, U301.17
unnamed: R323.2, U301.16
unnamed: R324.2, U301.15
unnamed: R325.2, TR301.1
unnamed: R327.2, TR302.1
unnamed: R404.2, R412.2, U401.6
unnamed: R406.2, R414.2, U402.6
unnamed: R407.1, U401.3
unnamed: R408.1, U401.5
unnamed: R409.1, U402.3
unnamed: R410.1, U402.5
unnamed: R412.1, R416.2, U401.7
unnamed: R414.1, R418.2, U402.7
unnamed: R425.2, U403.2, U403.6
unnamed: R426.2, U404.2, U404.6
VAA: C231.1, C232.1, C233.1, C234.1, D205.1, D207.2, L302.1, R208.1, U202.4
VCC: C201.1, C203.1, C205.1, C208.1, C226.1, C227.1, D202.2, D205.2, L202.1, U202.1, U202.2
VDD: C224.1, C225.1, C228.1, C229.1, C230.1, C235.1, C236.1, C237.1, C238.1, C321.1, C322.1, D204.1, D206.2, L301.1, R209.2, R301.1, R303.1, R304.1, R305.1, R306.1, R308.1, R309.1, R326.2, R328.2, U201.2, U302.4

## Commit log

2016-01-24 Release 1.0
    Release 1.0
    [ADC-PCM4202-SE-Bill-of-Materials-1.0.csv, ADC-PCM4202-SE-Bill-of-Materials-1.0.ods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]
2016-04-23 Revision 1.1
    [ADC-PCM4202-SE-1.1-Bill-of-Materials.csv, ADC-PCM4202-SE-1.1-Bill-of-Materials.ods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]

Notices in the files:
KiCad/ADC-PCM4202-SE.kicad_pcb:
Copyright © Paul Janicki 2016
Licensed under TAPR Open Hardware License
